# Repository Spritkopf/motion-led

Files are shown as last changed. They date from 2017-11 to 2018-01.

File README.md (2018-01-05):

## motion-led

Source code for the motion controlled led night light

### code

Firmware. This is a generic Makefile project. Building was tested using the GNU Arm Embedded toolchain.
Build with:

```bash
make BINPATH=<path/to/gnu/arm/embedded/toolchain/bin>     #(without trailing slash / !)
```

the BINPATH=... argument is not necessary if you have the binaries in your PATH

Also there are eclipse project files for use in eclipse with the Gnu Mcu Eclipse plugin. Use the "Import Existing Code" feature in eclipse

### pcb

PCB design data as well as gerber files

### cad

Contains everything related to the housing

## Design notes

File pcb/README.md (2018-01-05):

### PCB Design data

PCB design was created in KiCad

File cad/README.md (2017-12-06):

#### CAD-Files: Housing

Here are the CAD files for the 3D-printed housing. The models were created in Freecad (v0.17_pre). Also the STLs can be downloaded and printed directly

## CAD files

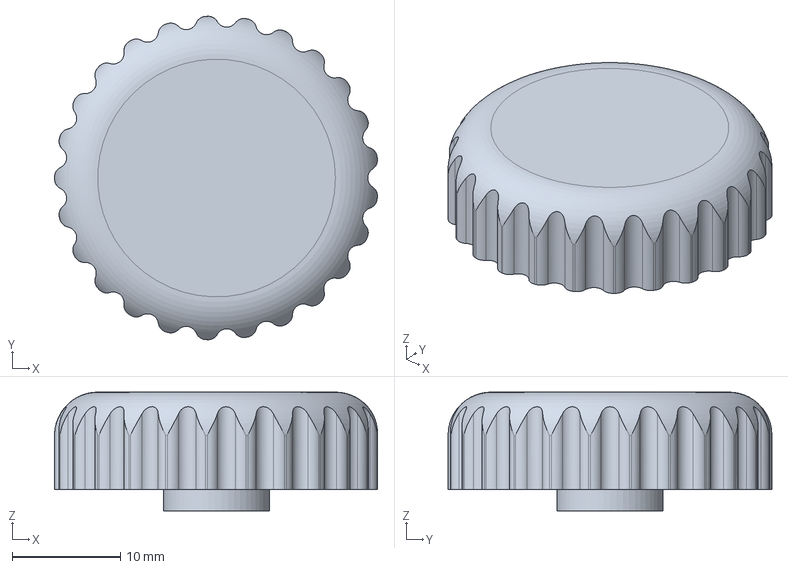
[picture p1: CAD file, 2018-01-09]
cad/3dprint/dial.step
29.9 x 30.0 x 11.0 mm

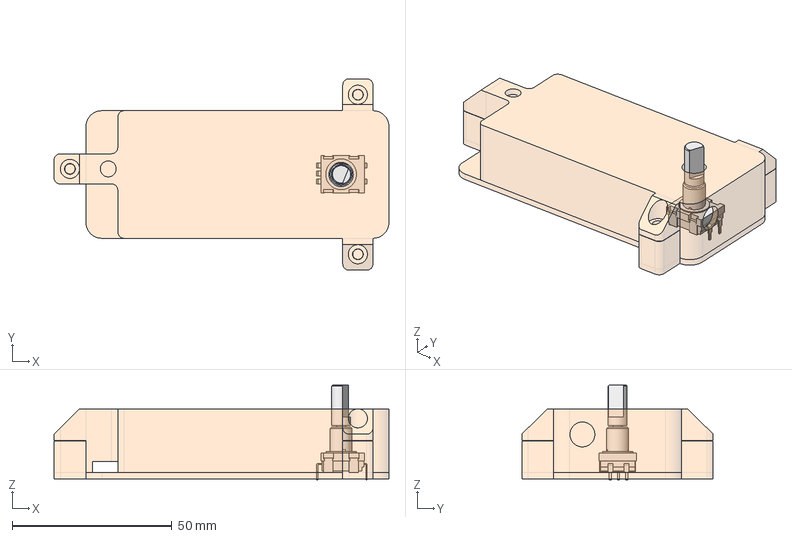
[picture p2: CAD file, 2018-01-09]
cad/housing.fcstd
105.0 x 60.0 x 29.7 mm
base
encoder
cover

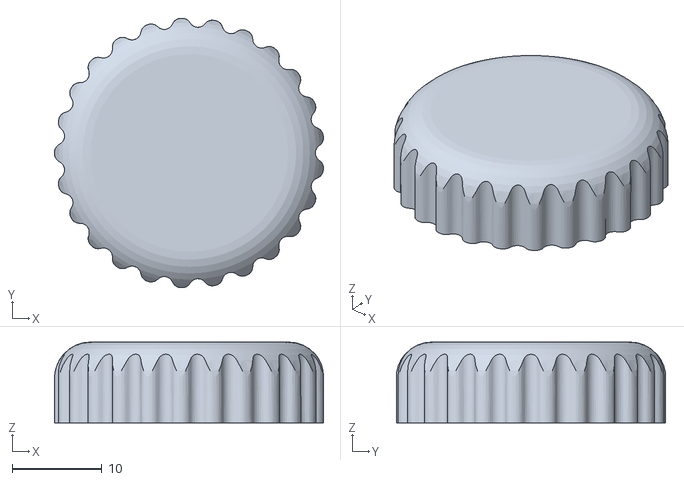
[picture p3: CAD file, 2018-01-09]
cad/3dprint/dial2.stl
29.9 x 30.0 x 9.00

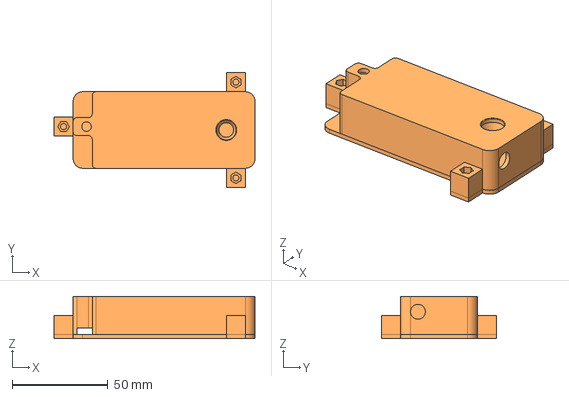
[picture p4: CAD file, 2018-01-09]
cad/housing2.fcstd
105.0 x 60.0 x 22.0 mm
base
cover

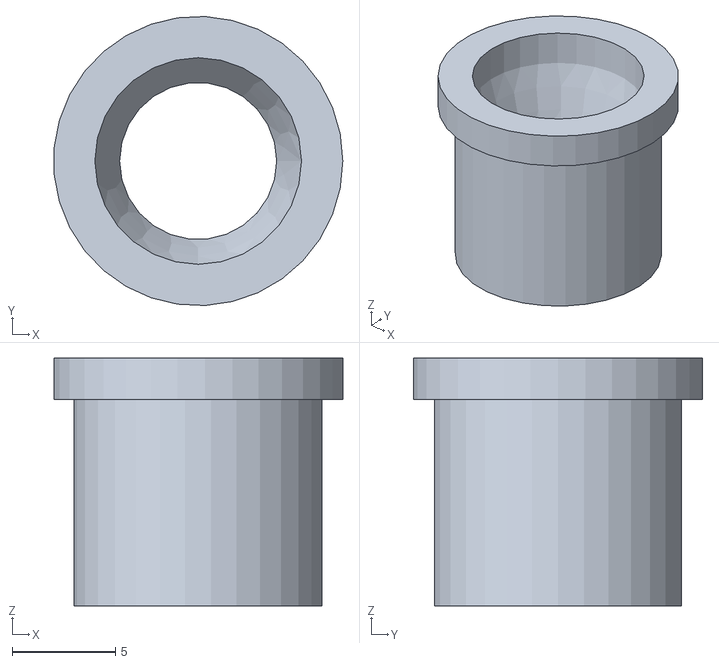
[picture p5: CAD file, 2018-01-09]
cad/3dprint/test3.stl
14.0 x 14.0 x 12.0

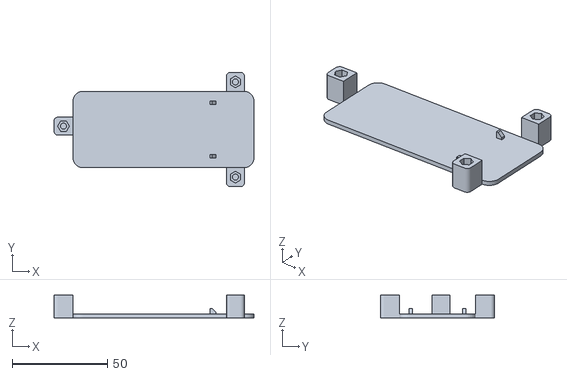
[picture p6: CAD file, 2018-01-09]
cad/3dprint/base.stl
105.0 x 60.0 x 12.0

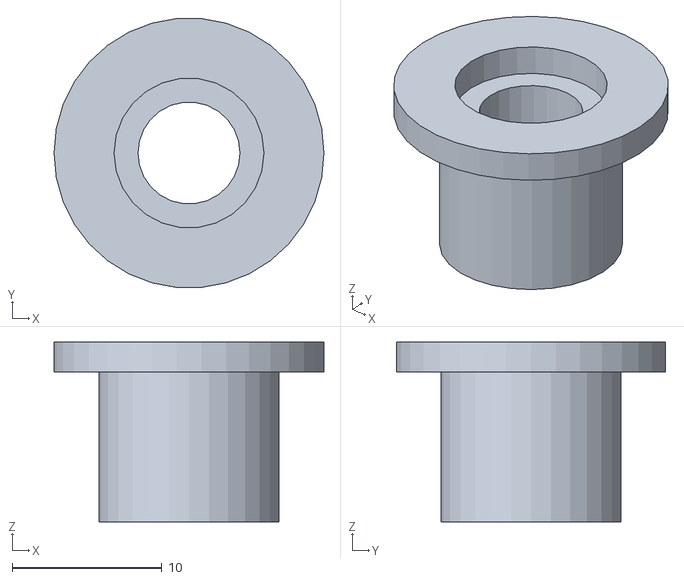
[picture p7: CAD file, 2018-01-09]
cad/3dprint/test2.stl
18.0 x 17.9 x 12.0

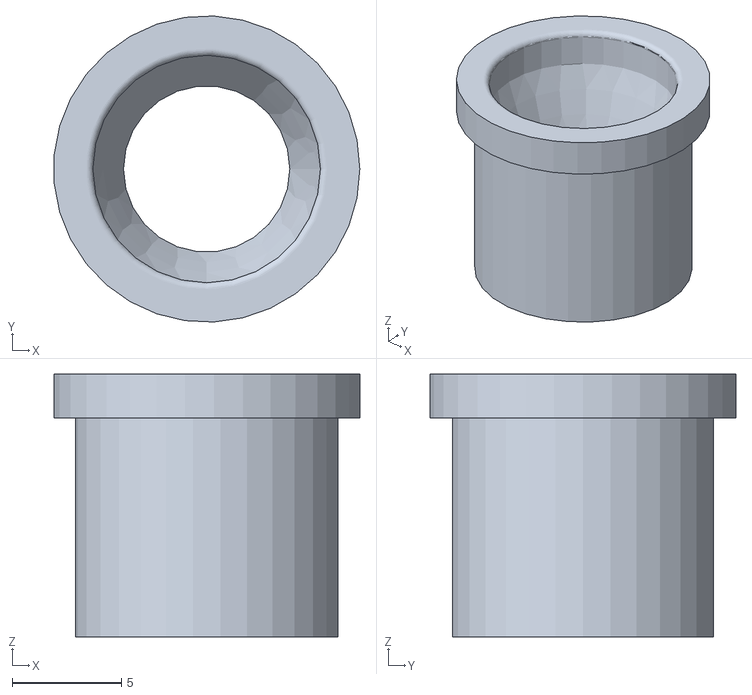
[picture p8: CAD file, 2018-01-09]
cad/3dprint/test4.stl
14.0 x 14.0 x 12.0

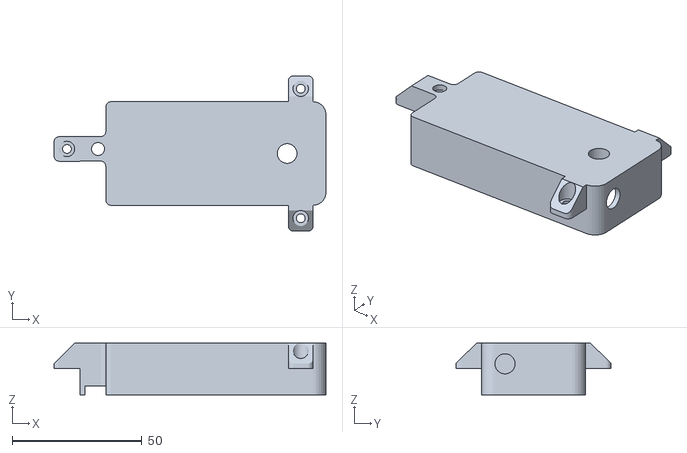
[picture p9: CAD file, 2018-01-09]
cad/3dprint/cover.stl
105.0 x 60.0 x 20.0

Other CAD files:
cad/3dprint/dial.stl

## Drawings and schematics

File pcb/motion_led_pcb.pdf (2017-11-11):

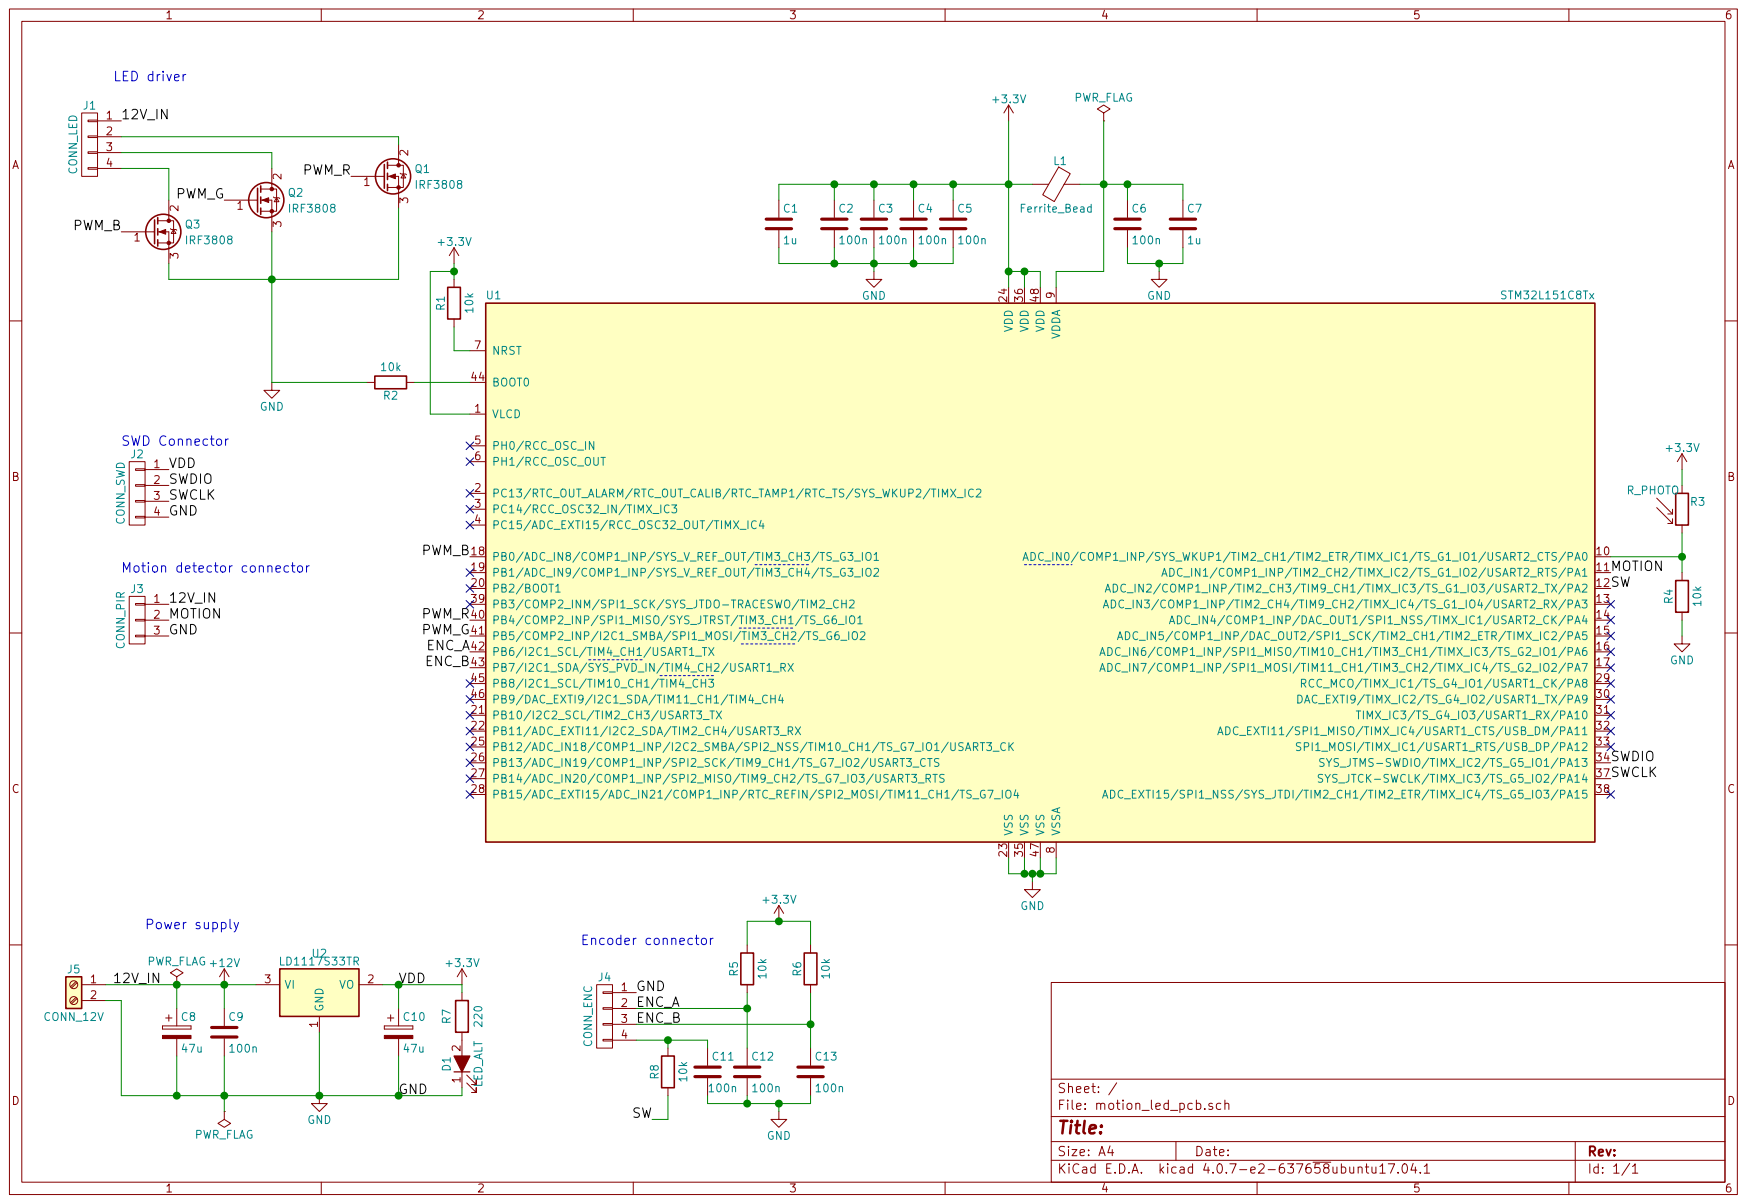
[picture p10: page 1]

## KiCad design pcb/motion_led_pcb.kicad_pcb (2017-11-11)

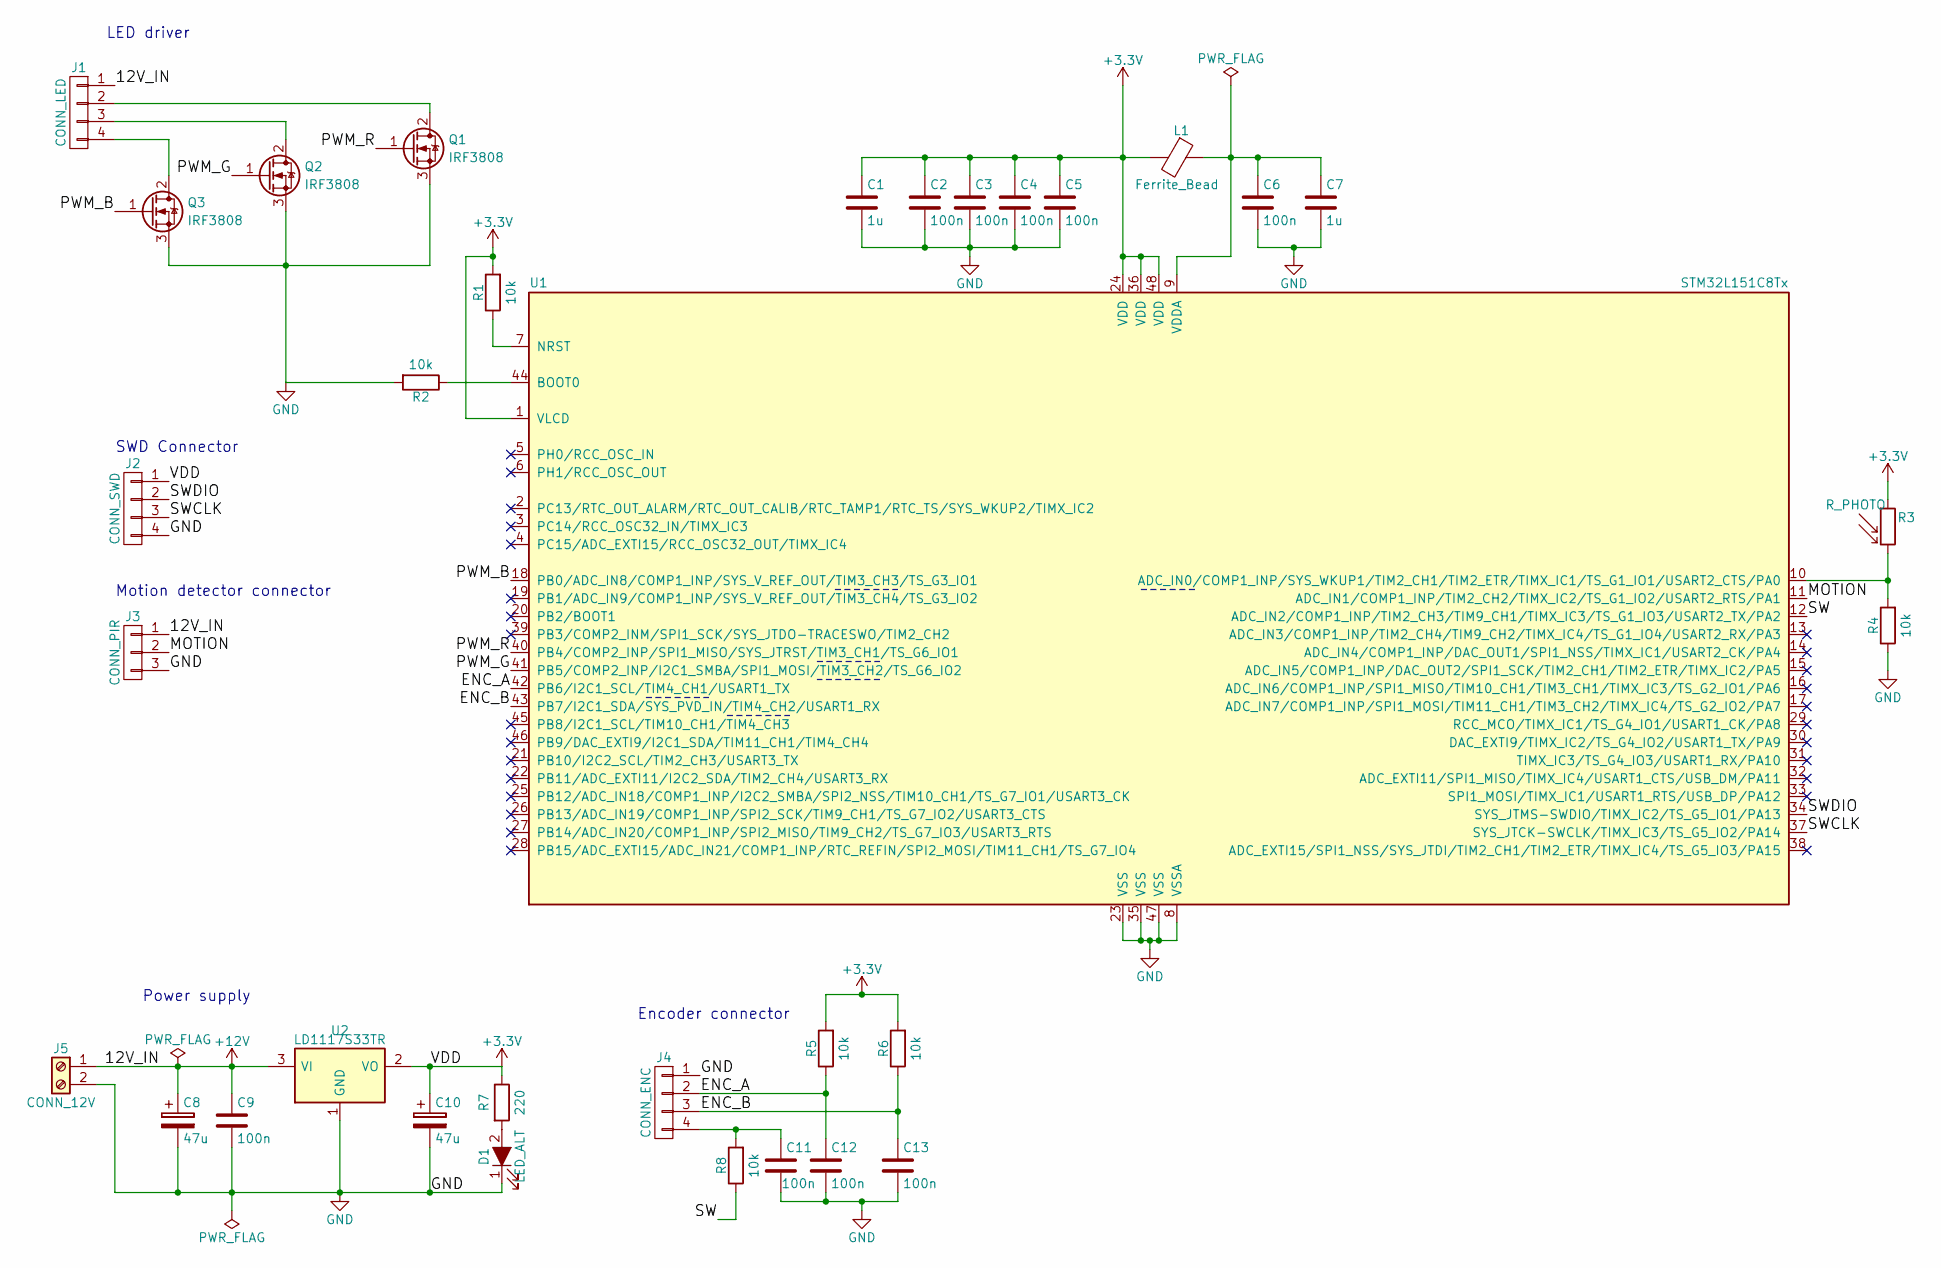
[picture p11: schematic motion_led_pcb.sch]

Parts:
C1, C7: 1u; C_1206_HandSoldering
C2, C3, C4, C5, C6, C9, C11, C12, C13: 100n; C_1206_HandSoldering
C8, C10: 47u; CP_Elec_10x10
D1: LED_ALT; LED_1206_HandSoldering
J1: CONN_LED; Pin_Header_Angled_1x04_Pitch2.54mm
J2: CONN_SWD; Pin_Header_Straight_1x04_Pitch2.54mm
J3: CONN_PIR; Pin_Header_Angled_1x04_Pitch2.54mm
J4: CONN_ENC; Pin_Header_Straight_1x04_Pitch2.54mm
J5: CONN_12V; TerminalBlock_WAGO-804_RM5mm_2pol
L1: Ferrite_Bead; L_0805_HandSoldering
Q1, Q2, Q3: IRF3808; TO-220_Vertical
R1, R2, R4, R5, R6, R8: 10k; R_1206_HandSoldering
R3: R_PHOTO; Pin_Header_Straight_1x02_Pitch2.54mm
R7: 220; R_1206_HandSoldering
U1: STM32L151C8Tx; LQFP-48_7x7mm_Pitch0.5mm
U2: LD1117S33TR; SOT-223

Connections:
+3V3: C1.1, C2.1, C3.1, C4.1, C5.1, C10.1, J2.1, L1.2, R1.2, R3.1, R5.2, R6.2, R7.1, U1.1 (VLCD), U1.24 (VDD), U1.36 (VDD), U1.48 (VDD), U2.2 (VO)
+12V: C8.1, C9.1, J1.1, J3.1, J5.1, U2.3 (VI)
/ENC_A: C12.1, J4.2, R5.1, U1.42 (PB6/I2C1_SCL/TIM4_CH1/USART1_TX)
/ENC_B: C13.1, J4.3, R6.1, U1.43 (PB7/I2C1_SDA/SYS_PVD_IN/TIM4_CH2/USART1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)
/MOTION: J3.2, U1.11 (ADC_IN1/COMP1_INP/TIM2_CH2/TIMX_IC2/TS_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)
/PWM_B: Q3.1 (G), U1.18 (PB0/ADC_IN8/COMP1_INP/SYS_V_REF_OUT/TIM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)
/PWM_G: Q2.1 (G), U1.41 (PB5/COMP2_INP/I2C1_SMBA/SPI1_MOSI/TIM3_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)
/PWM_R: Q1.1 (G), U1.40 (PB4/COMP2_INP/SPI1_MISO/SYS_JTRST/TIM3_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)
/SW: R8.1, U1.12 (ADC_IN2/COMP1_INP/TIM2_CH3/TIM9_CH1/TIM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)
/SWCLK: J2.3, U1.37 (SYS_JTCK-SWCLK/TIMX_IC3/TS_G5_IO2/PA14)
/SWDIO: J2.2, U1.34 (SYS_JTMS-SWDIO/TIMX_IC2/TS_G5_IO1/PA13)
GND: C1.2, C2.2, C3.2, C4.2, C5.2, C6.2, C7.2, C8.2, C9.2, C10.2, C11.2, C12.2, C13.2, D1.1 (K), J2.4, J3.3, J4.1, J5.2, Q1.3 (S), Q2.3 (S), Q3.3 (S), R2.2, R4.1, U1.8 (VSSA), U1.23 (VSS), U1.35 (VSS), U1.47 (VSS), U2.1 (GND); also elsewhere on the board
unnamed: C6.1, C7.1, L1.1, U1.9 (VDDA)
unnamed: C11.1, J4.4, R8.2
unnamed 14: D1.2 (A), R7.2; also elsewhere on the board
unnamed: J1.2, Q1.2 (D)
unnamed: J1.3, Q2.2 (D)
unnamed: J1.4, Q3.2 (D)
unnamed: R1.1, U1.7 (NRST)
unnamed: R2.1, U1.44 (BOOT0)
unnamed: R3.2, R4.2, U1.10 (ADC_IN0/COMP1_INP/SYS_WKUP1/TIM2_CH1/TI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)

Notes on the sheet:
Encoder connector
Power supply
LED driver
Motion detector connector
SWD Connector

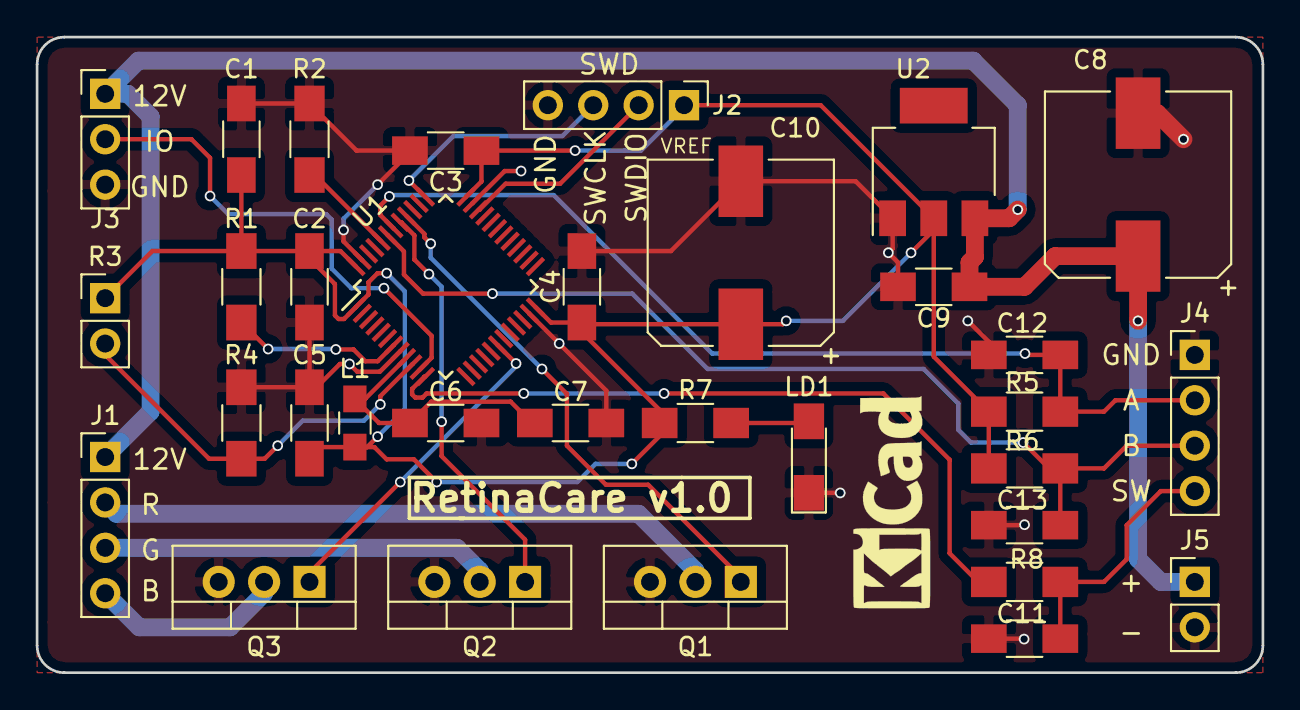
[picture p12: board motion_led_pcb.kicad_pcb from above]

Board: 2 copper layers, 68.6 x 35.6 mm, 33 parts (0 on the bottom side), 21 nets.

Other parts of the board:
LD1: LED_ALT; LED_1206_HandSoldering

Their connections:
GND: LD1.1; also elsewhere on the board
unnamed 14: LD1.2; also elsewhere on the board

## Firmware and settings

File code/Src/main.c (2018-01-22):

/*

 ******************************************************************************
 TODO: add license
 ******************************************************************************
 */
/* Includes ------------------------------------------------------------------*/
#include "stm32l1xx_hal.h"
#include "adc.h"
#include "gpio.h"
#include "pwm.h"
#include "encoder.h"
#include "motion_sensor.h"
#include "colorwheel.h"
#include "settings.h"
#include "rgb_led.h"
#include "light_sensor.h"

#define COLOR_HOLD_TIME				120000	/* time the light stays on (in ms) */
#define COLOR_FADEIN_TIME       	3000	/* time the light takes to fade in (in ms) */
#define COLOR_FADEOUT_TIME			8000	/* time the light takes to fade out (in ms) */
#define COLOR_FADE_FREQ				50		/* update rate when fading (in Hz) */

#define COLOR_FADE_STEP_DURATION 	(1000/COLOR_FADE_FREQ)
#define COLOR_FADEIN_MAX_STEPS 		(COLOR_FADEIN_TIME / COLOR_FADE_STEP_DURATION)
#define COLOR_FADEOUT_MAX_STEPS 	(COLOR_FADEOUT_TIME / COLOR_FADE_STEP_DURATION)

#define COLOR_SELECT_TIMEOUT				5000   /* timeout in color selection mode (when nothing is done, color resets to last values)*/
#define COLOR_SELECT_HUE_INCREMENT			5      /* the step size the hue changes when selecting the color by rotating the encoder */
#define COLOR_SELECT_BRIGHTNESS_INCREMENT	0.02   /* the step size the brightness changes when selecting the color by rotating the encoder */

/* type for states of state machine */
typedef enum {
    STATE_SLEEP = 0,
    STATE_WAKEUP = 1,
    STATE_COLOR_FADE_IN = 2,
    STATE_COLOR_HOLD = 3,
    STATE_COLOR_FADE_OUT = 4,
    STATE_COLOR_SET_HUE = 5,
    STATE_COLOR_SET_BRIGHTNESS = 6,
    STATE_COLOR_SAVE_VALUES = 7,
} state_t;

/* Private variables ---------------------------------------------------------*/

int8_t flag_encoder_rotation = 0; /* flag for encoder rotation (1=cw ; -1=ccw ; 0=nothing) */
uint8_t flag_encoder_button_pressed = 0; /* flag for encoder button press */
uint8_t flag_wakeup = 0; /* this flag will be set on motion detector interrupt */

state_t state = STATE_SLEEP;

uint32_t state_timeout_tick_start = 0;
uint32_t color_fade_current_step = 0;
uint32_t color_target_angle = 0;
float color_target_brightness = 0.0f;
uint32_t color_hold_time;

/* Private function prototypes -----------------------------------------------*/
static void SystemClock_Config(void);
static void SystemClockConfig_STOP(void);
static void SystemPower_Config(void);

void rotation_cb(uint8_t direction); /* callback for encoder rotation */
void button_cb(void); /* callback for button press */
void motion_cb(void); /* callback for motion detected */

int main(void) {

    /* MCU Configuration----------------------------------------------------------*/

    /* Reset of all peripherals, Initializes the Flash interface and the Systick. */
    HAL_Init();

    /* Configure the system clock */
    SystemClock_Config();
    SystemPower_Config();

    settings_init();
    color_target_angle = config_bank.angle;
    color_target_brightness = config_bank.brightness;
    rgb_led_current_color.angle = 0; /* blue for tests */
    rgb_led_current_color.brightness = 0.0f;

    /* Initialize remaining gpio pins for lower power consumption */
    MX_GPIO_Init();

    /* init RGB LED strip */
    rgb_led_init();

    /* init rotary encoder */
    encoder_init();
    encoder_set_rotation_callback(rotation_cb);
    encoder_set_button_callback(button_cb);
    encoder_start();

    motion_sensor_init(motion_cb);

    light_sensor_init();

    /* Infinite loop */
    while (1) {

        /* enter state machine */
        switch (state) {
        case STATE_SLEEP:
        {

        	/* turn off leds */
        	rgb_led_current_color.brightness = 0.0f;
        	rgb_led_update_color();
        	HAL_Delay(50);
        	rgb_led_update_color();	/* second time since sometimes one or more channels are not turned off correctly */
        	HAL_Delay(150);

        	light_sensor_deinit();  /* deactivate adc for even lower power consumption */

        	HAL_Delay(50);

        	HAL_PWR_EnterSTOPMode(PWR_LOWPOWERREGULATOR_ON, PWR_STOPENTRY_WFI);  /* enter ultra low power mode */

        	SystemClockConfig_STOP();  /* after wakeup, reconfigure system clock */

        	HAL_Delay(150);

        	/* re-enable ADC */
        	light_sensor_init();

        	state = STATE_WAKEUP;

            break;
        }

        case STATE_WAKEUP:
        {

        	if (flag_wakeup == 1)
        	{
				flag_wakeup = 0;

				/* only proceed if it is actually dark outside, otherwise go back to sleep */
				if (light_sensor_get_value() <= LIGHT_SENSOR_THRESHOLD) {

					/* prepare fade in */
					rgb_led_current_color.angle = color_target_angle;
					state_timeout_tick_start = HAL_GetTick();
					color_fade_current_step = 0;
					color_hold_time = COLOR_HOLD_TIME;
					state = STATE_COLOR_FADE_IN;
				}
				else {
					/* go back to sleep */
					state = STATE_SLEEP;
				}
        	}

            break;
        }

        case STATE_COLOR_FADE_IN:
        {
        	/* if during fade in the light sensor detects more light than was measured when saving the preset,
        	 * it is presumed that an external light was turned on. Therefore, turn LEDs off and return to sleep
        	 */
        	if(light_sensor_get_value() > config_bank.adc_value +250)
        	{
        		state = STATE_SLEEP;
        		break;
        	}

            if ((HAL_GetTick() - state_timeout_tick_start) >= COLOR_FADE_STEP_DURATION) {
                rgb_led_current_color.brightness = color_target_brightness
                        * (float) ((float) color_fade_current_step
                                / (float) COLOR_FADEIN_MAX_STEPS);
                rgb_led_update_color();
                color_fade_current_step++;
                state_timeout_tick_start = HAL_GetTick();
            }

            if (color_fade_current_step >= COLOR_FADEIN_MAX_STEPS) {
                /* fading finished */
                rgb_led_current_color.brightness = color_target_brightness;
                rgb_led_update_color();

                /* prepare hold */
                state_timeout_tick_start = HAL_GetTick();
                state = STATE_COLOR_HOLD;
            }

            break;
        }

        case STATE_COLOR_HOLD:
        {
        	/* if during hold time the light sensor detects more light than was measured when saving the preset,
			 * it is presumed that an external light was turned on. Therefore, turn LEDs off and return to sleep
			 */
			if(light_sensor_get_value() > (config_bank.adc_value + 250))
			{
				state = STATE_SLEEP;
				break;
			}

            if ((HAL_GetTick() - state_timeout_tick_start) >= color_hold_time) {
                /* holding time is over, check if there was a recent motion (sensor signal is still high) */
                if(motion_sensor_get_state() == 1)
                {
                    /* keep lights on 10 seconds longer */
                    state_timeout_tick_start -= 10000;
                }
                else
                {
                    /* prepare fade out */
                    state_timeout_tick_start = HAL_GetTick();
                    color_fade_current_step = COLOR_FADEOUT_MAX_STEPS;
                    flag_wakeup = 0;
                    state = STATE_COLOR_FADE_OUT;
                }
            }
            break;
        }
        case STATE_COLOR_FADE_OUT:
        {
            if ((HAL_GetTick() - state_timeout_tick_start)
                    >= COLOR_FADE_STEP_DURATION) {
                rgb_led_current_color.brightness = color_target_brightness
                        * (float) ((float) color_fade_current_step / (float) COLOR_FADEOUT_MAX_STEPS);
                rgb_led_update_color();
                color_fade_current_step--;
                state_timeout_tick_start = HAL_GetTick();
            }

            /* if a motion occurred during fade-out, turn light back on for 30 more seconds */
            if(flag_wakeup == 1)
            {
                flag_wakeup = 0;
                rgb_led_current_color.brightness = color_target_brightness;
                rgb_led_update_color();
                color_hold_time = 30000;
                state = STATE_COLOR_HOLD;
            }

            if (color_fade_current_step == 0) {
                /* fading finished */
                rgb_led_current_color.brightness = 0;
                rgb_led_update_color();
                state_timeout_tick_start = 0;
                state = STATE_SLEEP;
            }
            break;
        }
        case STATE_COLOR_SET_HUE:
        {
            if (flag_encoder_rotation == 1) {
                flag_encoder_rotation = 0;
                state_timeout_tick_start = HAL_GetTick();
                if (rgb_led_current_color.angle > 350) {
                    rgb_led_current_color.angle = 0;
                }
                rgb_led_current_color.angle += COLOR_SELECT_HUE_INCREMENT;
                rgb_led_update_color();
            }
            if (flag_encoder_rotation == -1) {
                flag_encoder_rotation = 0;
                state_timeout_tick_start = HAL_GetTick();
                if (rgb_led_current_color.angle < COLOR_SELECT_HUE_INCREMENT) {
                    rgb_led_current_color.angle = 360;
                }
                rgb_led_current_color.angle -= COLOR_SELECT_HUE_INCREMENT;
                rgb_led_update_color();
            }
            if (flag_encoder_button_pressed == 1) {
                flag_encoder_button_pressed = 0;
                state_timeout_tick_start = HAL_GetTick();
                state = STATE_COLOR_SET_BRIGHTNESS;

                /* blink once to signal confirmation */
                rgb_led_current_color.brightness = 0.0;
                rgb_led_update_color();
                HAL_Delay(100);
                rgb_led_current_color.brightness = color_target_brightness;
                rgb_led_update_color();
            }
            if ((HAL_GetTick() - state_timeout_tick_start)
                    >= COLOR_SELECT_TIMEOUT) {
                rgb_led_current_color.brightness = 0.0;
                rgb_led_update_color();
                state = STATE_SLEEP;
            }
            break;
        }
        case STATE_COLOR_SET_BRIGHTNESS:
        {
            if (flag_encoder_rotation == -1) {
                flag_encoder_rotation = 0;
                state_timeout_tick_start = HAL_GetTick();
                if (rgb_led_current_color.brightness >= 1.0f) {
                    rgb_led_current_color.brightness = 1.0f;
                }
                rgb_led_current_color.brightness +=
                COLOR_SELECT_BRIGHTNESS_INCREMENT;
                rgb_led_update_color();
            }
            if (flag_encoder_rotation == 1) {
                flag_encoder_rotation = 0;
                state_timeout_tick_start = HAL_GetTick();
                if (rgb_led_current_color.brightness
                        < COLOR_SELECT_BRIGHTNESS_INCREMENT) {
                    rgb_led_current_color.brightness = 0.0;
                }
                rgb_led_current_color.brightness -=
                COLOR_SELECT_BRIGHTNESS_INCREMENT;
                rgb_led_update_color();
            }
            if (flag_encoder_button_pressed == 1) {
                flag_encoder_button_pressed = 0;
                state = STATE_COLOR_SAVE_VALUES;
            }
            if ((HAL_GetTick() - state_timeout_tick_start)
                    >= COLOR_SELECT_TIMEOUT) {
                rgb_led_current_color.brightness = 0.0;
                rgb_led_update_color();
                state = STATE_SLEEP;
            }
            break;
            case STATE_COLOR_SAVE_VALUES:
            {
                color_target_angle = rgb_led_current_color.angle;
                color_target_brightness = rgb_led_current_color.brightness;

                /* save in EEPROM */
                config_bank.angle = color_target_angle;
                config_bank.brightness = color_target_brightness;
                config_bank.adc_value = light_sensor_get_value();
                settings_save();

                /* blink twice to signal confirmation */
                rgb_led_current_color.brightness = 0.0;
                rgb_led_update_color();
                HAL_Delay(100);
                rgb_led_current_color.brightness = color_target_brightness;
                rgb_led_update_color();
                HAL_Delay(150);
                rgb_led_current_color.brightness = 0.0;
                rgb_led_update_color();
                HAL_Delay(100);
                rgb_led_current_color.brightness = color_target_brightness;
                rgb_led_update_color();
                HAL_Delay(150);
                rgb_led_current_color.brightness = 0.0;
                rgb_led_update_color();

                state = STATE_SLEEP;
                break;
            }
        }
        default:
            state = STATE_SLEEP;
            break;
        }

        /* evaluate button press */
        if (flag_encoder_button_pressed == 1) {
            if ((state != STATE_COLOR_SET_HUE)
                    && (state != STATE_COLOR_SET_BRIGHTNESS)) {
                flag_encoder_button_pressed = 0;
                /* turn on LED and enter color selection mode */
                rgb_led_current_color.brightness = color_target_brightness;
                rgb_led_current_color.angle = color_target_angle;
                rgb_led_update_color();
                state_timeout_tick_start = HAL_GetTick();
                state = STATE_COLOR_SET_HUE;
            }

        }

    }

}

/** System Clock Configuration (generated by CubeMX)
 */
void SystemClock_Config(void) {

    RCC_OscInitTypeDef RCC_OscInitStruct;
    RCC_ClkInitTypeDef RCC_ClkInitStruct;

    /* enable clock for PWR peripheral */
    __HAL_RCC_PWR_CLK_ENABLE();

    /**Configure the main internal regulator output voltage 
     */
    __HAL_PWR_VOLTAGESCALING_CONFIG(PWR_REGULATOR_VOLTAGE_SCALE1);

    /**Initializes the CPU, AHB and APB busses clocks 
     */
    RCC_OscInitStruct.OscillatorType = RCC_OSCILLATORTYPE_HSI;
    RCC_OscInitStruct.HSIState = RCC_HSI_ON;
    RCC_OscInitStruct.HSICalibrationValue = 16;
    RCC_OscInitStruct.PLL.PLLState = RCC_PLL_ON;
    RCC_OscInitStruct.PLL.PLLSource = RCC_PLLSOURCE_HSI;
    RCC_OscInitStruct.PLL.PLLMUL = RCC_PLL_MUL3;
    RCC_OscInitStruct.PLL.PLLDIV = RCC_PLL_DIV4;
    if (HAL_RCC_OscConfig(&RCC_OscInitStruct) != HAL_OK) {
    }

    /**Initializlight_sensores the CPU, AHB and APB busses clocks
     */
    RCC_ClkInitStruct.ClockType = RCC_CLOCKTYPE_HCLK | RCC_CLOCKTYPE_SYSCLK
            | RCC_CLOCKTYPE_PCLK1 | RCC_CLOCKTYPE_PCLK2;
    RCC_ClkInitStruct.SYSCLKSource = RCC_SYSCLKSOURCE_PLLCLK;
    RCC_ClkInitStruct.AHBCLKDivider = RCC_SYSCLK_DIV1;
    RCC_ClkInitStruct.APB1CLKDivider = RCC_HCLK_DIV1;
    RCC_ClkInitStruct.APB2CLKDivider = RCC_HCLK_DIV1;

    if (HAL_RCC_ClockConfig(&RCC_ClkInitStruct, FLASH_LATENCY_0) != HAL_OK) {
    }

    /**Configure the Systick interrupt time 
     */
    HAL_SYSTICK_Config(HAL_RCC_GetHCLKFreq() / 1000);

    /**Configure the Systick 
     */
    HAL_SYSTICK_CLKSourceConfig(SYSTICK_CLKSOURCE_HCLK);

    /* SysTick_IRQn interrupt configuration */
    HAL_NVIC_SetPriority(SysTick_IRQn, 0, 0);
}


void SystemPower_Config(void){
   __HAL_RCC_PWR_CLK_ENABLE();
   HAL_PWREx_EnableUltraLowPower();
   HAL_PWREx_EnableFastWakeUp();
   //HAL_PWR_DisableSleepOnExit();
}

/**
  * @brief  Configures system clock after wake-up from STOP: enable HSI, PLL
  *         and select PLL as system clock source.
  * @param  None
  * @retval None
  */
static void SystemClockConfig_STOP(void)
{
  RCC_ClkInitTypeDef RCC_ClkInitStruct = {0};
  RCC_OscInitTypeDef RCC_OscInitStruct = {0};

  /* Enable Power Control clock */
  __HAL_RCC_PWR_CLK_ENABLE();

  /* The voltage scaling allows optimizing the power consumption when the device is
     clocked below the maximum system frequency, to update the voltage scaling value
     regarding system frequency refer to product datasheet.  */
  __HAL_PWR_VOLTAGESCALING_CONFIG(PWR_REGULATOR_VOLTAGE_SCALE1);

  /* Poll VOSF bit of in PWR_CSR. Wait until it is reset to 0 */
  while (__HAL_PWR_GET_FLAG(PWR_FLAG_VOS) != RESET) {};

  /* Get the Oscillators configuration according to the internal RCC registers */
  HAL_RCC_GetOscConfig(&RCC_OscInitStruct);

  /* After wake-up from STOP reconfigure the system clock: Enable HSI and PLL */
  RCC_OscInitStruct.OscillatorType      = RCC_OSCILLATORTYPE_HSI;
  RCC_OscInitStruct.HSEState            = RCC_HSE_OFF;
  RCC_OscInitStruct.HSIState            = RCC_HSI_ON;
  RCC_OscInitStruct.PLL.PLLState        = RCC_PLL_ON;
  RCC_OscInitStruct.PLL.PLLSource       = RCC_PLLSOURCE_HSI;
  RCC_OscInitStruct.HSICalibrationValue = 16;
  RCC_OscInitStruct.PLL.PLLMUL          = RCC_PLL_MUL3;
  RCC_OscInitStruct.PLL.PLLDIV          = RCC_PLL_DIV4;
  HAL_RCC_OscConfig(&RCC_OscInitStruct);

  /* Select PLL as system clock source and configure the HCLK, PCLK1 and PCLK2
     clocks dividers */
  RCC_ClkInitStruct.ClockType = RCC_CLOCKTYPE_SYSCLK;
  RCC_ClkInitStruct.SYSCLKSource = RCC_SYSCLKSOURCE_PLLCLK;
  HAL_RCC_ClockConfig(&RCC_ClkInitStruct, FLASH_LATENCY_1);
}



void rotation_cb(uint8_t direction) {
    if (direction) {
        flag_encoder_rotation = 1;
    }
    else {
        flag_encoder_rotation = -1;
    }
}

void button_cb(void) {
    flag_encoder_button_pressed = 1;
}

void motion_cb(void) {
    flag_wakeup = 1;
}

/* Interrupt callback for GPIO interrupts */
void HAL_GPIO_EXTI_Callback(uint16_t GPIO_Pin) {
    if (GPIO_Pin == ENCODER_BTN_PIN) {
        encoder_button_interrupt_handler();
    }

    if (GPIO_Pin == MOTION_SENSOR_GPIO_PIN) {
        motion_sensor_interrupt_handler();
    }
}

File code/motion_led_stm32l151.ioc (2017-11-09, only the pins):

Mcu.UserName=STM32L151C8Tx
PA0-WKUP1.GPIO_Label=PHOTO_R
PA0-WKUP1.Signal=ADC_IN0
PA1.GPIO_Label=MOTION
PA1.Signal=GPXTI1
PA13.Signal=SYS_JTMS-SWDIO
PA14.Signal=SYS_JTCK-SWCLK
PA2.GPIO_Label=ENC_BTN
PA2.Signal=GPXTI2
PB0.GPIO_Label=PWM_Blue
PB0.Signal=S_TIM3_CH3
PB4.GPIO_Label=PWM_Red
PB4.Signal=S_TIM3_CH1
PB5.GPIO_Label=PWM_Green
PB5.Signal=S_TIM3_CH2
PB6.GPIO_Label=ENC_A
PB6.Signal=S_TIM4_CH1
PB7.GPIO_Label=ENC_B
PB7.Signal=S_TIM4_CH2

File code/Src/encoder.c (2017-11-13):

/*
 * encoder.c
 *
 *  Created on: 13.03.2016
 *      Author: Spritkopf
 */

#include "stm32l1xx_hal.h"
#include "encoder.h"

#define CH_A_HIGH	HAL_GPIO_ReadPin(GPIOE, GPIO_PIN_11)==GPIO_PIN_SET
#define CH_A_LOW	HAL_GPIO_ReadPin(GPIOE, GPIO_PIN_11)==GPIO_PIN_RESET
#define CH_B_HIGH	HAL_GPIO_ReadPin(GPIOA, GPIO_PIN_8)==GPIO_PIN_SET
#define CH_B_LOW	HAL_GPIO_ReadPin(GPIOA, GPIO_PIN_8)==GPIO_PIN_RESET
#define THRESHOLD	300

#define ENCODER_PIN_A	 GPIO_PIN_6
#define ENCODER_PIN_B	 GPIO_PIN_7
#define ENCODER_PORT	 GPIOB
#define ENCODER_BTN_PIN	 GPIO_PIN_2
#define ENCODER_BTN_PORT GPIOA


/* Timer handler declaration */
TIM_HandleTypeDef    encoder_handle;


static uint32_t encoder_get_direction();

/* function pointer for callback functions */
void (*encoder_rotation_callback)(uint8_t direction);
void (*encoder_button_callback)(void);


void TIM4_IRQHandler(void)
{
	uint8_t temp_direction;

	HAL_TIM_IRQHandler(&encoder_handle);

	temp_direction = encoder_get_direction();
	encoder_rotation_callback(temp_direction);

	/* Wait a short delay before clearing Interrupt flags to avoid
	 * immediately following interrupts due to bouncing issues
	 *  todo: remove this, we have hardware debouncing */
	//delay = 0xfff0;
	//while(delay--);

}



void encoder_init()
{
	GPIO_InitTypeDef   gpio;
	TIM_Encoder_InitTypeDef encoder_config;

	/* Encoder Pins
	 *
	 * A: PA8
	 * B: PE11
	 * Button: PA6
	 */


	/* Enable GPIO Channels Clock */
	__HAL_RCC_GPIOA_CLK_ENABLE();
	__HAL_RCC_GPIOB_CLK_ENABLE();
	__HAL_RCC_TIM4_CLK_ENABLE();

	HAL_NVIC_SetPriority(TIM4_IRQn, 0, 1);
	HAL_NVIC_EnableIRQ(TIM4_IRQn);


	/*##-2- Configure I/Os #####################################################*/
	/* Common configuration for all channels */
	gpio.Pin = ENCODER_PIN_A | ENCODER_PIN_B;
	gpio.Mode = GPIO_MODE_AF_PP;
	gpio.Pull = GPIO_NOPULL;
	gpio.Speed = GPIO_SPEED_HIGH;
	gpio.Alternate = GPIO_AF2_TIM4;

	/* Channel 2 configuration */
	HAL_GPIO_Init(ENCODER_PORT, &gpio);

	/* Push Button Initialization */
	gpio.Pin = ENCODER_BTN_PIN;
	gpio.Mode = GPIO_MODE_IT_FALLING;
	gpio.Pull = GPIO_PULLUP;
	gpio.Speed = GPIO_SPEED_HIGH;
	HAL_GPIO_Init(ENCODER_BTN_PORT, &gpio);

	HAL_NVIC_SetPriority(EXTI2_IRQn, 0, 2);
	HAL_NVIC_EnableIRQ(EXTI2_IRQn);

	encoder_handle.Instance = TIM4;
	encoder_handle.Init.Period = 0xFFFF;
	encoder_handle.Init.Prescaler = 0;
	encoder_handle.Init.ClockDivision = 0;
	encoder_handle.Init.CounterMode = TIM_COUNTERMODE_UP;

	encoder_config.EncoderMode = TIM_ENCODERMODE_TI2;
	encoder_config.IC1Polarity = TIM_ICPOLARITY_FALLING;
	encoder_config.IC1Selection = TIM_ICSELECTION_DIRECTTI;
	encoder_config.IC1Prescaler = TIM_ICPSC_DIV1;
	encoder_config.IC1Filter = 0x0F;

	encoder_config.IC2Polarity = TIM_ICPOLARITY_BOTHEDGE;
	encoder_config.IC2Selection = TIM_ICSELECTION_DIRECTTI;
	encoder_config.IC2Prescaler = TIM_ICPSC_DIV1;
	encoder_config.IC2Filter = 0x0F;

	HAL_TIM_Encoder_Init(&encoder_handle, &encoder_config);




}

void encoder_start(void)
{
	/* Start the encoder interface */
	HAL_TIM_Encoder_Start_IT(&encoder_handle, TIM_CHANNEL_1);
}

void encoder_stop(void)
{
	HAL_TIM_Encoder_Stop_IT(&encoder_handle, TIM_CHANNEL_1);
}

uint32_t encoder_get_direction(void)
{
	return (__HAL_TIM_IS_TIM_COUNTING_DOWN(&encoder_handle));
}

void encoder_set_rotation_callback(void (*user_callback)(uint8_t direction))
{
	encoder_rotation_callback = user_callback;
}

void encoder_set_button_callback(void (*user_callback)(void))
{
	encoder_button_callback = user_callback;

}

void encoder_button_interrupt_handler(void)
{
	if(encoder_button_callback != NULL)
	{
		encoder_button_callback();
	}
}

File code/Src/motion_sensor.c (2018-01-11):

/*
 * motion_sensor.c
 *
 *  Created on: 31.08.2017
 *      Author: ricardo
 */

#include "stm32l1xx_hal.h"
#include "motion_sensor.h"

#define MOTION_SENSOR_GPIO_CLK_ENABLE	__HAL_RCC_GPIOA_CLK_ENABLE
#define MOTION_SENSOR_GPIO_PORT			GPIOA
#define MOTION_SENSOR_GPIO_PIN			GPIO_PIN_1
#define MOTION_SENSOR_IRQN				EXTI1_IRQn

void (*motion_callback)(void);

void motion_sensor_init(void(*cb)(void))
{
	GPIO_InitTypeDef gpio;

	MOTION_SENSOR_GPIO_CLK_ENABLE();

	gpio.Pin = MOTION_SENSOR_GPIO_PIN;
	gpio.Mode = GPIO_MODE_IT_RISING;
	gpio.Speed = GPIO_SPEED_LOW;
	gpio.Pull = GPIO_PULLDOWN;

	HAL_GPIO_Init(MOTION_SENSOR_GPIO_PORT, &gpio);

	HAL_NVIC_SetPriority(MOTION_SENSOR_IRQN, 15, 4);
	HAL_NVIC_EnableIRQ(MOTION_SENSOR_IRQN);

	/* register callback */
	motion_callback = cb;

}

uint8_t motion_sensor_get_state(void)
{
    if(HAL_GPIO_ReadPin(MOTION_SENSOR_GPIO_PORT, MOTION_SENSOR_GPIO_PIN) == GPIO_PIN_SET)
    {
        return (1);
    }
    else
    {
        return (0);
    }
}

void motion_sensor_interrupt_handler()
{
	if(motion_callback != NULL)
	{
		motion_callback();
	}
}

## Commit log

2017-08-23 added pwm and colorwheel modules, pwm verified working
2017-11-09 first version of fw for final board based on STM32L1
    - working hardware layer for LED-strip pwm
    - working hardware layer for rotary encoder
    - test programm: blink red / blue when rotating the encoder
    - cleanup of repository: remove stm32f4discovery test project
    - add LICENSE
2017-11-11 add encoder button functionality
    [motion_led_pcb-B.Cu.gbr, motion_led_pcb-B.Mask.gbr, motion_led_pcb-B.Paste.gbr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]
2017-11-11 - add .gitignore (do not upload build directory / binaries) - add motion sensor module - some generalization regarding interrupt handling (introducing callback hell)
2017-11-24 - introduced statemachine + refactoring
    - main program logic handled by state machine (not yet finished)
    - added motino sensor
    - working: fading in and out when a motion is detected
    - refactoring: added a abstraction layer for the rgb_led so the
    pwm/colorwheel handling gets less confusing
    - changed structure of persistent memory, now hold only color angle and
    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
2017-11-27 Add color selection
    - pushing button enters color selection mode. The leds will show current
    hue and brightness. Rotating the encoder will change hue. Select desired
    color with button press. LEDs will blink shortly to confirm selection.
    - after selecting hue, brightness selection mode is entered. Rotating
    the encoder will change brightness. Select desired brightness with
    button press. LEDs will blink twice shortly to confirm selection. The
    selected LED selection will be saved to eeprom.
    - timeout in selection mode aborts and discard any changes
    [main.c]
2017-11-29 add light sensor
    - add adc module for reading photoresistor voltage
    - add module "light_sensor" as wrapper for adc
    - while waking up, the firmware checks the ADC threshold and continues
    only if it is dark outside
    - threshold can be changed in file light_sensor.c
    - todo: add low power modes
2017-12-06 begin model of housing
    [housing.fcstd]
2017-12-07 further work on housing
    [housing.fcstd]
2018-01-05 Revert "further work on housing"
    This reverts commit a4d4fc7b077d78782a1bc928010f73d2f7b85a85.
    [housing.fcstd]
2018-01-05 Revert "Revert "further work on housing""
    This reverts commit 258873a0c46fc528692b93963fde2261351ec5b1.
    [housing.fcstd]
2018-01-09 introduced low power mode
    - device enters "STOP" mode
    - wakeup when interupts occur (motion sensor or rotary encoder)
    - needs testing / confirmation
2018-01-09 - first version finished
    - sleep mode tested
    - added missing CAD parts
    - set time the lights will stay on to 2 minutes
    [base.stl, cover.stl, dial.step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]
2018-01-11 try out STOP mode which needs even less power than sleep mode.
2018-01-11 improved behavior when turning off
    The time the light stays on is no longer fixed. If a movement is
    recognized at the end of the on-time, the light will stay on for 10
    additional seconds (The motion sensor has to be configured in
    "repeatable trigger" mod so that the output stays high as long there is
    movement)
    If a movement occurs during fade-out, the light will turn back on for
    additional 30 seconds before fading out again
    [main.c, motion_sensor.c]
2018-01-11 - fixed encoder rotation
    - clockwise to increase brightness feels more natural
    [main.c]
2018-01-13 new feature: turn off if external light is detected after wakeup
    - light sensor value is saved when chosing color/brightness
    - if light sensor reads more than this value at/after fade-in, it is
    assumed that an external light is switched on and sleep mode is entered
